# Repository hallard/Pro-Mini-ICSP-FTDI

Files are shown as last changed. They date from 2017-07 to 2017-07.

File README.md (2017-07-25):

Arduino Pro Mini ICSP and FTDI Programming Board
================================================

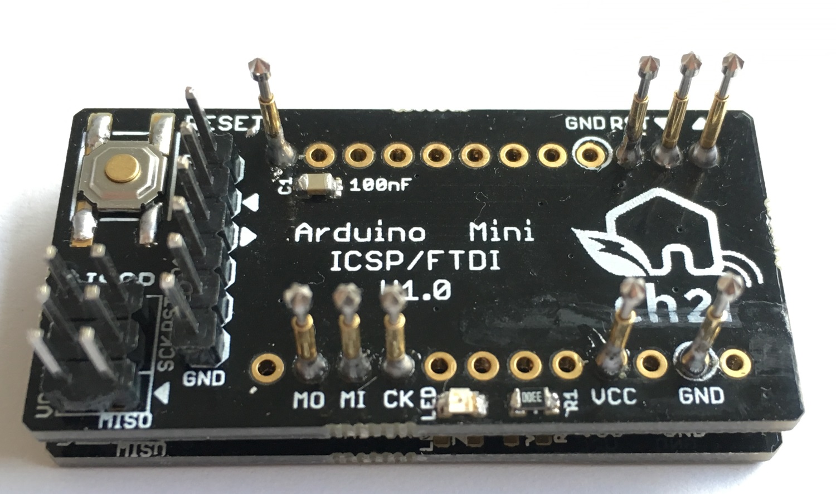
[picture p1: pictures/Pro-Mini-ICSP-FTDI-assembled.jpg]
Board
  

This shield is used to flash my Arduino Pro Mini with [OptiBoot](https://github.com/Optiboot/optiboot) bootloader and to upload sketch to it. Optiboot is less Flash consuming than classic one.

Also, for 3V3 at 8MHz devices, upload at 57600 is slow, so I'm using 250KBPS upload. You can see [here](https://hallard.me/ulpnode-bootloader-1/) why and how to. 
So, I can upload faster and more than that, Optiboot is using 0.5K of flash instead of 2K, it's a double win configuration, especially with huge sketch like LoraWan device with LMIC stack for my [Mini LORA Board](https://www.thethingsnetwork.org/forum/t/8059/).

**Features**   

- ICSP 6 pins connector
- FTDI 6 pins connector
- Power LED
- Reset button

**Got V1.0 Boards from [PCBs.io](https://PCBs.io). I tested them, all is fine**

Detailed Description
====================

Nothing special to say, it's just some wiring, ICSP pins for programming (Power+SPI+Reset), FTDI (Power+Reset+RX+TX) for flashing and a LED to power the board (see if ICSP connector is fitted with good pining)

I'm using 2 PCB boards stacked with pogo pins and this avoid soldering any headers to the Mini Boards. 

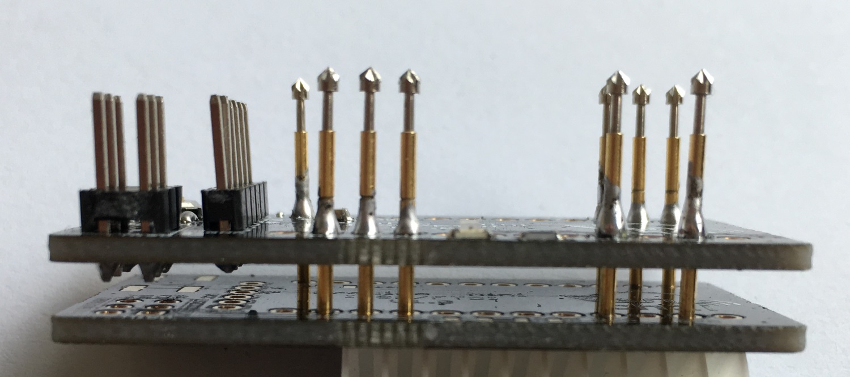
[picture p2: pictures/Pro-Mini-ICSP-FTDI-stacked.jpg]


Schematics
==========

Click on image to zoom   
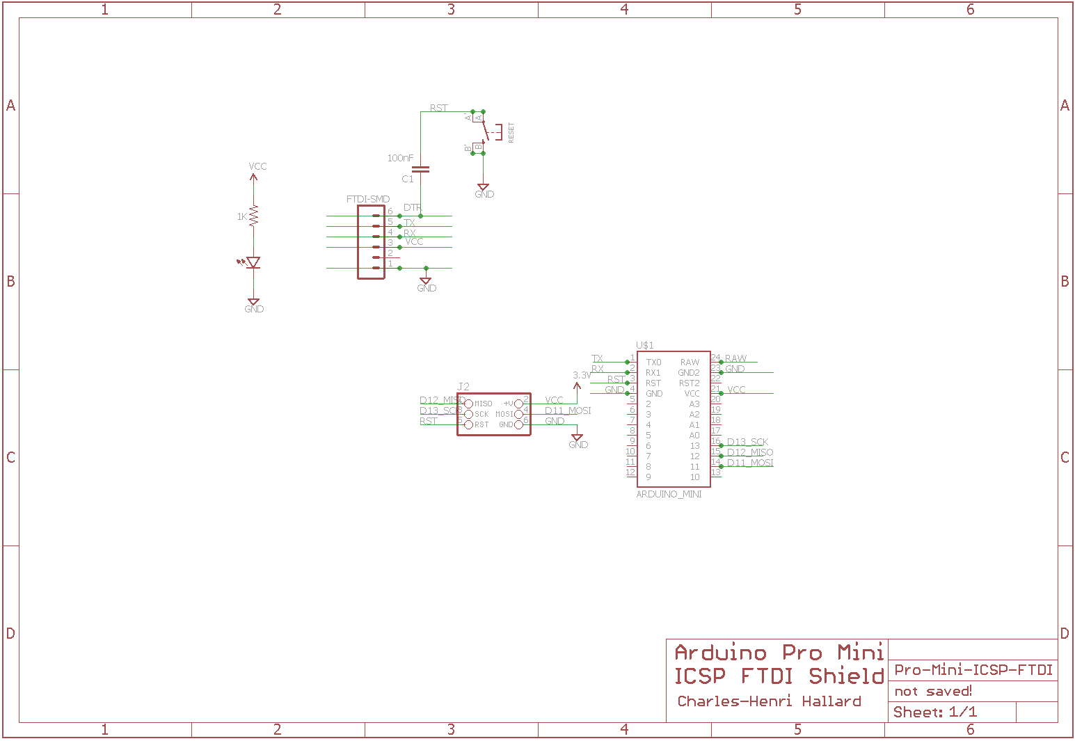
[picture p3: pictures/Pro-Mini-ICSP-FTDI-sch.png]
schematic
  

Boards
====== 

**Top**

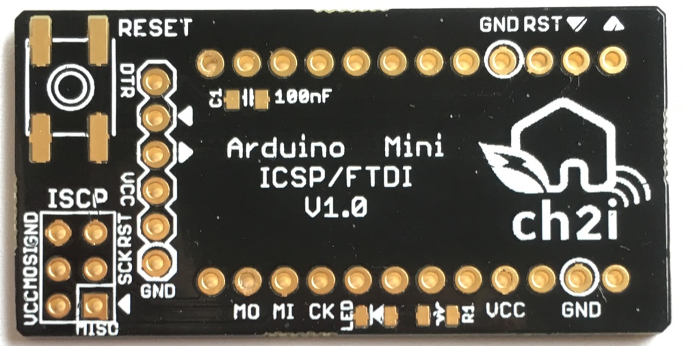
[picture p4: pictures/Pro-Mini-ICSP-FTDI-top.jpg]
Top


**Bottom**

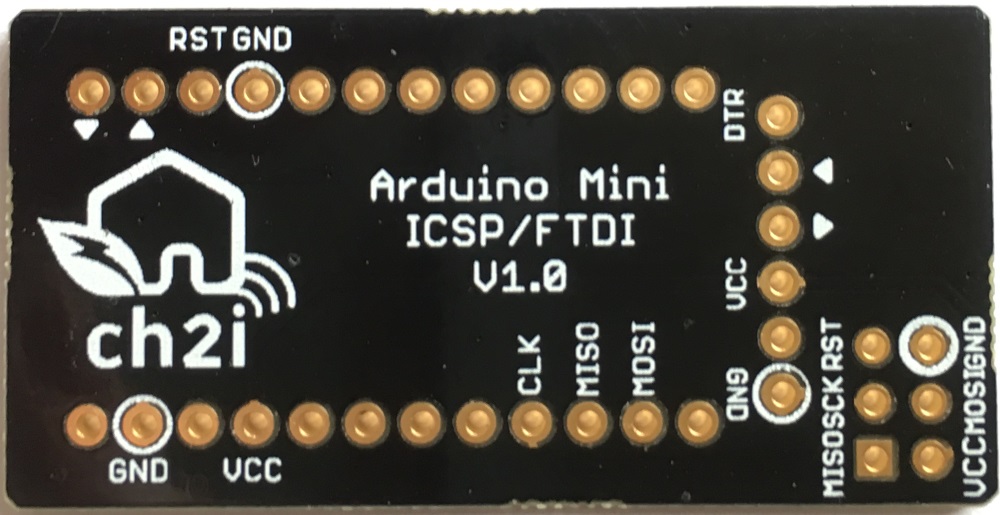
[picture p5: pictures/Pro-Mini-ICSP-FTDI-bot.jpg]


You can order PCB at [PCBs.io](https://PCBs.io/share/rm2v2). PCBs.io give me reward when you order my designed boards from their site. This is pretty good, because I can use these rewards to create and design new boards and order boards for a discounted price and share new boards. So if you don't care about PCB manufacturer please use PCBs.io.

Assembled boards (V1.0)
=======================

**Populated**

Bottom

**With Arduino Pro Mini on it**

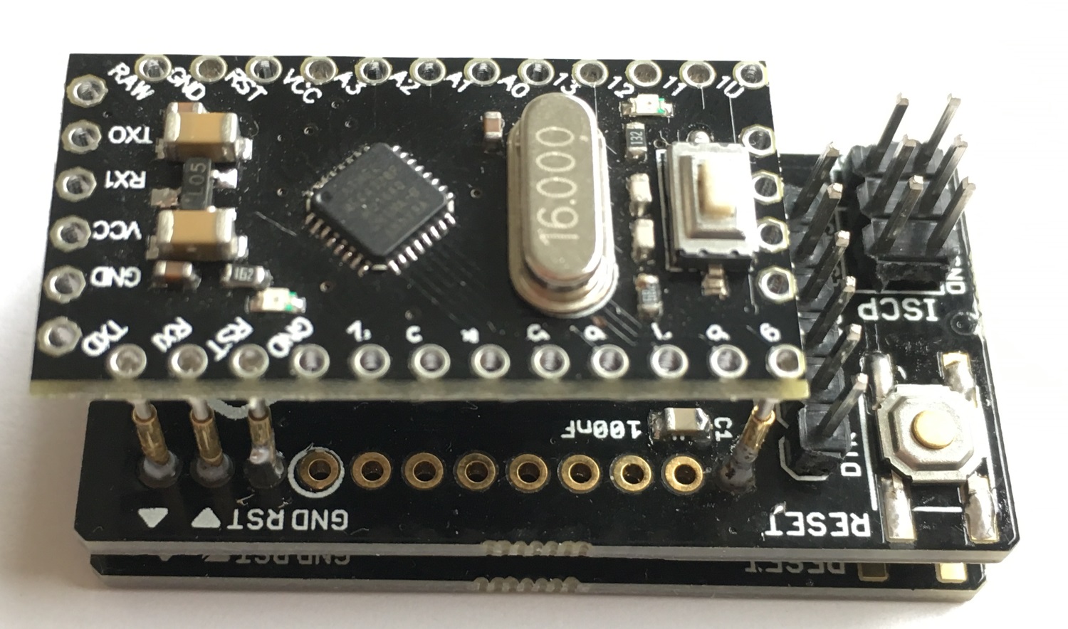
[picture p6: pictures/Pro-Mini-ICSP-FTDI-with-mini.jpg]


Bootloaders
===========

I've compiled some [bootloaders](https://github.com/hallard/Pro-Mini-ICSP-FTDI/tree/master/bootloaders) for you, use the one you prefer, I'm using:

- optiboot_flash_atmega328p_250000_8MHZ.hex (250KBPS) on 3V3 8MHz Mini
- optiboot_flash_atmega328p_250000_16MHZ.hex on 5V 16MHz Mini

I tested the 1MB ones, works fine also, here below the configuration of Fuses and Lockbit I'm using.

**Fuse configuration**

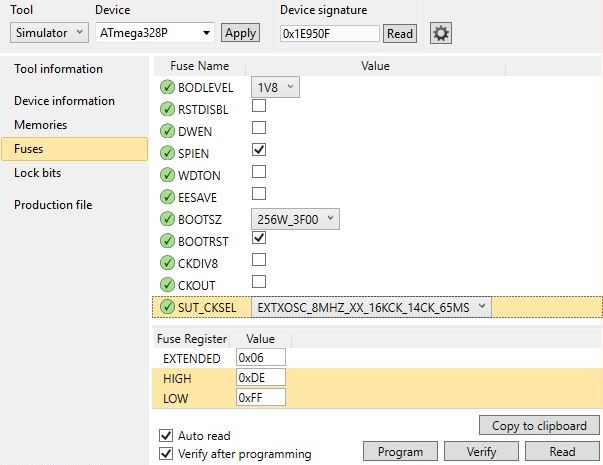
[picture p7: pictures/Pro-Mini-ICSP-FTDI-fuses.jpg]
Fuses


**Lockbit**

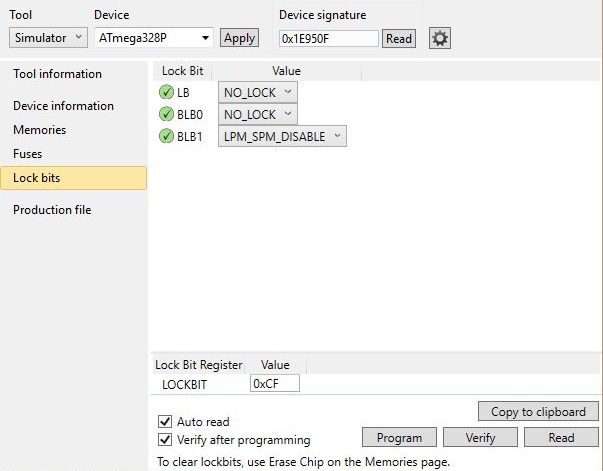
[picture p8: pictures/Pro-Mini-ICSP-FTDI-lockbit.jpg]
Lockbit


License
=======


This work is licensed under a Creative Commons Attribution-NonCommercial 4.0 International [License](http://creativecommons.org/licenses/by-nc/4.0)

If you want to do commercial stuff with this project, please contact [CH2i company](https://ch2i.eu) so we can organize an simple agreement.

Misc
====
See news and other projects on my [blog](https://hallard.me)

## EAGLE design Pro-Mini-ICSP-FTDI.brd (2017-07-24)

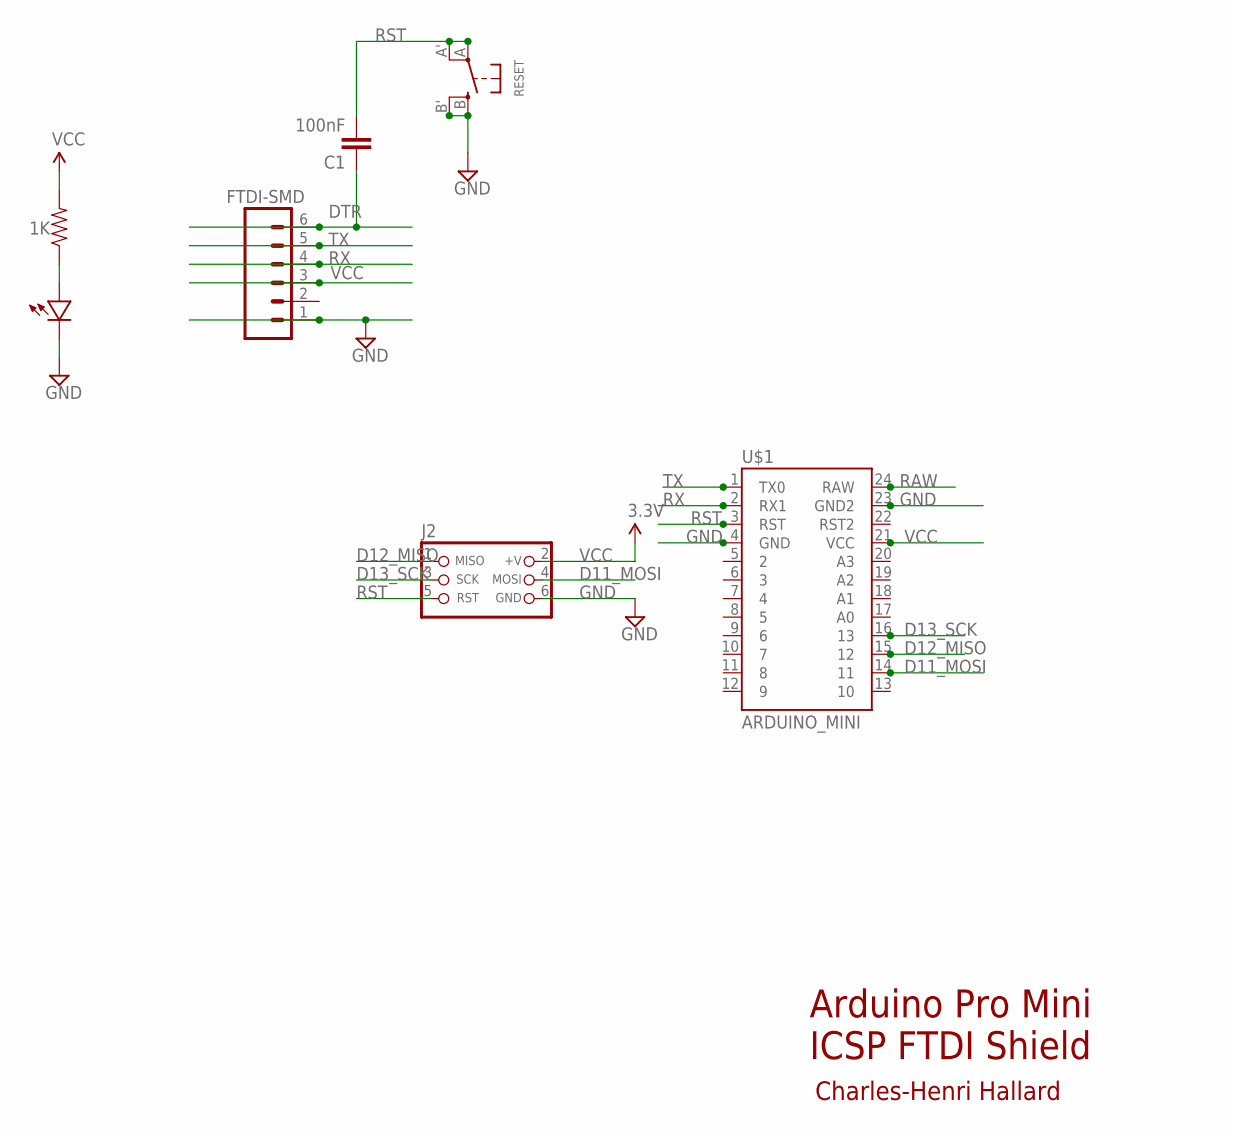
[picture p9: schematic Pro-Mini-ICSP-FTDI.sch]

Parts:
C1: 100nF; 0805-CAP
FTDI-SMD: SMD; 1X06
J2: CON_HEADER_PRG_AVR_ICSP-PTH; HEADER_PRG_2X03
R1: 1K; 0805-RES
RESET: SWITCH_TACT_SMT; EVQ-Q2
U$1: ARDUINO_MINI
U$2: LED0805; 0805-LED

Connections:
D11_MOSI: J2.4 (MOSI), U$1.14 (11)
D12_MISO: J2.1 (MISO), U$1.15 (12)
D13_SCK: J2.3 (SCK), U$1.16 (13)
DTR: C1.1, FTDI-SMD.6
GND: FTDI-SMD.1, J2.6 (GND), RESET.B (S), RESET.B' (S1), U$1.4 (GND), U$1.23 (GND2), U$2.MINUS
unnamed: R1.1, U$2.PLUS
RAW: U$1.24 (RAW)
RST: C1.2, J2.5 (RST), RESET.A, RESET.A' (P1), U$1.3 (RST)
RX: FTDI-SMD.4, U$1.2 (RX1)
TX: FTDI-SMD.5, U$1.1 (TX0)
VCC: FTDI-SMD.3, J2.2 (+V), R1.2, U$1.21 (VCC)

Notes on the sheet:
Arduino Pro Mini ICSP FTDI Shield
Charles-Henri Hallard

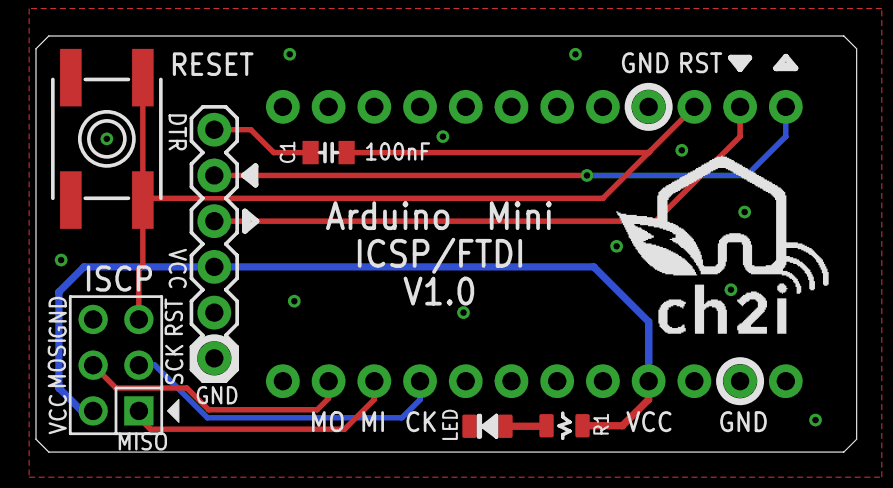
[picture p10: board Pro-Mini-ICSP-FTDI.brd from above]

Board: 2 copper layers, 45.6 x 23.1 mm, 9 parts (1 on the bottom side), 10 nets.

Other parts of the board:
U$3, U$4: LOGO_CH2I_110MM

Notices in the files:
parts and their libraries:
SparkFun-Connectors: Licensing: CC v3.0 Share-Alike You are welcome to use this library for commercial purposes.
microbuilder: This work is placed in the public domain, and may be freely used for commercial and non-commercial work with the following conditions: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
